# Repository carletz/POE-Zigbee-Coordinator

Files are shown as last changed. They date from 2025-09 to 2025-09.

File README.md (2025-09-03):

# Zigbee Coordinator with Ethernet and PoE Support

This project is a custom-designed Zigbee Coordinator board integrating **ESP32**, **Zigbee RF module (RF-BM-2652P2)**, and **Ethernet with Power over Ethernet (PoE)** capabilities. It is optimized for smart home or industrial IoT gateway applications, and provides a compact, PoE-powered solution for reliable Zigbee-to-IP bridging.

## Features

- **ESP32-WROOM-32UE** microcontroller with Wi-Fi and Bluetooth
- **Zigbee RF module (CC2652-based)** for Zigbee 3.0 coordination
- **LAN8720A Ethernet PHY** connected to ESP32 via RMII
- **PoE power supply** using TPS2376DDAR IEEE 802.3af-compliant PD controller
- Fully isolated and filtered power stages for 3.3V and 5V rails
- **CH340C USB-UART converter** for easy flashing/debugging
- USB Type-C input with ESD protection
- JTAG and serial debug headers
- LEDs for link/activity indication
- Compact design ready for fabrication via JLCPCB

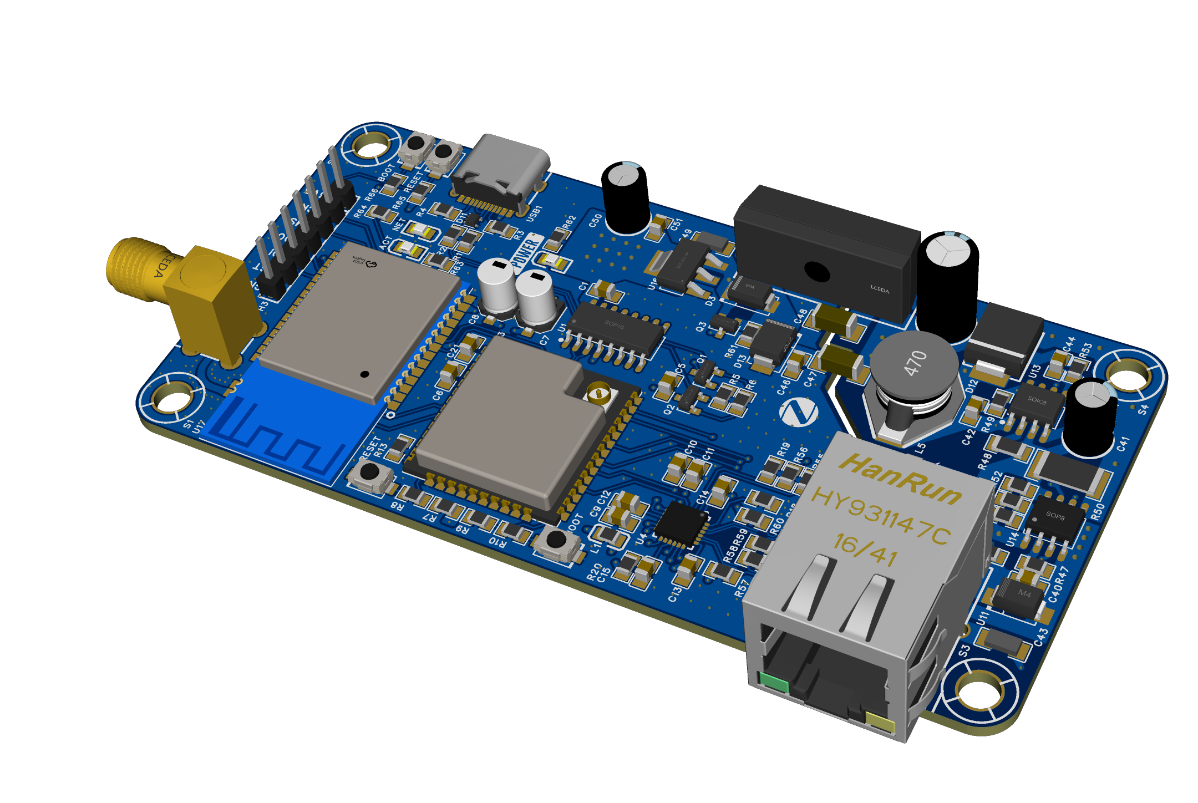
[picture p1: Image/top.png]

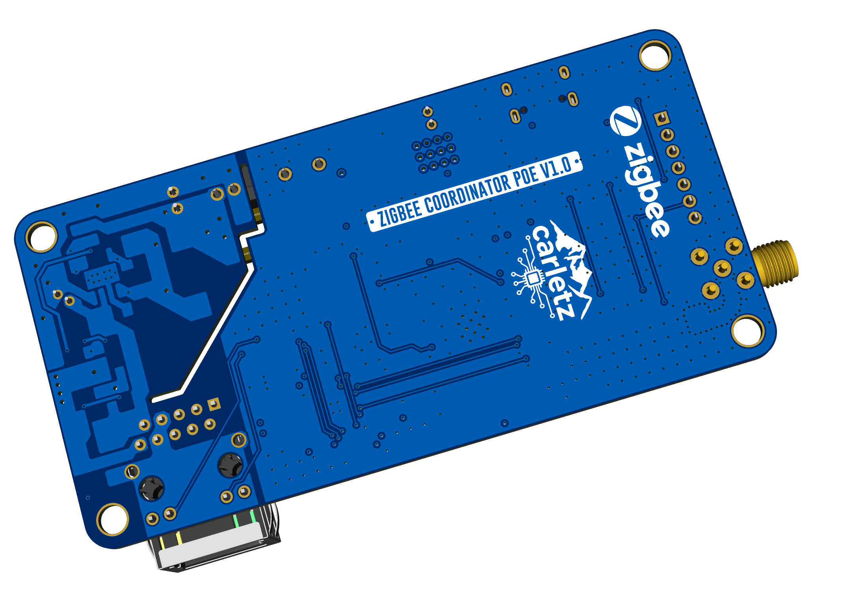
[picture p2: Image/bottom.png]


## Project Structure

The electrical schematic is divided into the following pages:
1. **Ethernet & PoE**: LAN8720A, RJ45 + magnetics, PoE PD and DC/DC conversion
2. **Controller**: ESP32 core, CH340C UART, USB input, power rails
3. **Zigbee Module**: RF-BM-2652P2, antenna, buttons, debug interfaces

## Tools & Compatibility

- Designed in **EasyEDA**
- Compatible with **Zigbee2MQTT**, **Home Assistant**, **OpenHAB**, and other automation platforms
- ESP32 flashable via USB or UART boot mode (IO0 + EN)
- Zigbee module (CC2652P2) flashable via UART bridge with ESP32

## Flashing Instructions

### ESP32
1. Flash the ESP32 using a serial tool or over USB with your preferred firmware (e.g., ESPHome, custom UART bridge, etc.).
   A special thanks to the work of [ZigStar](https://zig-star.com/) crew where I took a lot of inspiration

### CC2652P2 Zigbee Module
1. Use the ESP32 to create a UART bridge to the CC2652P2 module.
2. Access the ESP32 on the configured IP address via TCP/UDP.
3. Download the appropriate Zigbee coordinator firmware from (in dev branch folder):
   [Koenkk Z-Stack firmware](https://github.com/Koenkk/Z-Stack-firmware/tree/dev/coordinator/Z-Stack_3.x.0/bin)
4. Flash the CC2652P2 using tools like `cc2538-bsl` or TI's SmartRF Flash Programmer through the ESP32 UART bridge.

## Getting Started

1. Assemble the PCB using the schematic and a compatible BOM.
2. Flash ESP32 and configure the Zigbee module as described above.
3. Connect the board via Ethernet or Wi-Fi.
4. Integrate with your MQTT broker and Zigbee network.

## License

This project is open hardware, released under the MIT License.

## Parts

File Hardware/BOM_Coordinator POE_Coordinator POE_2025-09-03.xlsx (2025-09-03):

No. | Quantity | Comment | Designator | Footprint | Value | Manufacturer Part | Manufacturer | Supplier Part | Supplier | LCSC Stock | LCSC Price | Primary Category | Secondary Category | Pin Count | JLCPCB Stock | JLCPCB Price | 3D Model Title | Device | Name | Unique ID | Convert to PCB | Add into BOM | Symbol | Layer | Mounting Style
1 | 3 | XL-2012SURC | ((POWER)),ACT,NET | LED0805-R-RD |  | XL-2012SURC | XINGLIGHT(成兴光) | C965812 | LCSC |  |  | Optoelectronics | LED Indication - Discrete | 2 | 798816 | 0.0008 | LED0805-RD-1 | XL-2012SURC | XL-2012SURC | gge156_1,gge305,gge306 |  | yes |  | T | SMT
2 | 4 | TS-1088-AR02016 | BOOT,BOOT,RESET,RESET | SW-SMD_L3.9-W3.0-P4.45 |  | TS-1088-AR02016 | XUNPU(讯普) | C720477 | LCSC |  |  | Switches | Tactile Switches | 2 | 369929 | 0.0061 | SW-SMD_L3.9-W2.9-H2.0-LS4.8 | TS-1088-AR02016 | TS-1088-AR02016 | gge95_1,gge98_1,gge98_2,gge98_3 |  | yes |  | T | SMT
3 | 10 | 100nF | C1,C11,C12,C13,C14,C15,C21,C40,C42,C51 | C0805 | 100nF | CL21B104KCFNNNE | SAMSUNG(三星) | C28233 | LCSC |  |  | Capacitors | Multilayer Ceramic Capacitors MLCC - SMD/SMT | 2 | 946782 | 0.0009 | C0805_L2.0-W1.3-H1.3 | CL21B104KCFNNNE | 100nF | gge212,gge212_1,gge212_2,gge212_3,gge212_4,gge213_2,gge214_2,gge216,gge216_2,gge251 |  | yes |  | T | SMT
4 | 1 | 1uF | C5 | C0805 | 1uF | HHV0805R7105K101NSLJ | Chinocera(华瓷) | C22367837 | LCSC |  |  | Capacitors | Multilayer Ceramic Capacitors MLCC - SMD/SMT | 2 | 71386 | 0.0037 | C0805_L2.0-W1.3-H1.3 | HHV0805R7105K101NSLJ | 1uF | gge251_1 |  | yes |  | T | SMT
5 | 3 | 10uF | C6,C9,C10 | C0805 | 10uF | CL21A106KOQNNNE | SAMSUNG(三星) | C1713 | LCSC |  |  | Capacitors | Multilayer Ceramic Capacitors MLCC - SMD/SMT | 2 | 1508588 | 0.0013 | C0805_L2.0-W1.3-H1.3 | CL21A106KOQNNNE | 10uF | gge199,gge199_1,gge200 |  | yes |  | T | SMT
6 | 2 | 10uF | C7,C8 | CAP-SMD_BD4.0-L4.3-W4.3-LS5.1-FD | 10uF | VE-100M1ATR-0405 | lelon(立隆) | C249449 | LCSC |  |  | Capacitors | Aluminum Electrolytic Capacitors - SMD | 2 | 1 | 0.0083 | CAP-SMD_BD4.0-L4.3-W4.3-LS5.1-FD | VE-100M1ATR-0405 | 10uF | gge137_1,gge138_1 |  | yes |  | T | SMT
7 | 1 | 15uF | C41 | CAP-TH_BD5.0-P2.00-D0.8-FD | 15uF | LKMB1102A150MF | Ymin(永铭) | C443117 | LCSC |  |  | Capacitors | Aluminum Electrolytic Capacitors - Leaded | 2 | 1593 | 0.009 | CAP-TH_D5.0×H7.0×P2.0 | LKMB1102A150MF | 15uF | gge269_1 |  | yes |  | T | DIP
8 | 1 | 1nF | C43 | C1206 | 1nF | HHV1206R7102K202NSLJ | Chinocera | C5186823 | LCSC |  |  | Capacitors | Multilayer Ceramic Capacitors MLCC - SMD/SMT | 2 | 0 | 0.0019 | C1206_L3.2-W1.6-H1.3 | CC1206KKX7RDBB102 | 1nF | gge275_1 |  | yes |  | T | SMT
9 | 1 | 12pF | C44 | C0805 | 12pF | 0805CG120J500NT | FH(风华) | C1792 | LCSC |  |  | Capacitors | Multilayer Ceramic Capacitors MLCC - SMD/SMT | 2 | 112563 | 0.0007 | C0805_L2.0-W1.3-H1.3 | 0805CG120J500NT_C1792 | 12pF | gge277_1 |  | yes |  | T | SMT
10 | 1 | 470uF | C45 | CAP-TH_BD6.3-P2.50-D1.0-FD | 470uF | NXB10V470M6.3*11 LO | SAMYOUNG(韩国三莹) | C371106 | LCSC |  |  | Capacitors | Aluminum Electrolytic Capacitors - Leaded | 2 | 61 | 0.0103 | CAP-TH_BD6.3-P2.50-D1.0-FD | NXB10V470M6.3*11 LO | 470uF | gge280_1 |  | yes |  | T | DIP
11 | 1 | 22uF | C46 | C0805 | 22uF | CL21A226MQQNNNE | SAMSUNG(三星) | C5674 | LCSC |  |  | Capacitors | Multilayer Ceramic Capacitors MLCC - SMD/SMT | 2 | 3551136 | 0.0016 | C0805_L2.0-W1.3-H1.3 | CL21A226MQQNNNE | 22uF | gge284_1 |  | yes |  | T | SMT
12 | 2 | 1nF | C47,C48 | C1808 | 1nF | 1808B102K302NT | FH(风华) | C967608 | LCSC |  |  | Capacitors | Multilayer Ceramic Capacitors MLCC - SMD/SMT | 2 | 17403 | 0.0077 | C1808_L4.5-W2.0-H2.0 | 1808B102K302NT | 1nF | gge307_1,gge308_1 |  | yes |  | T | SMT
13 | 1 | 10uF | C49 | C1206 | 10uF | CL31A106KBHNNNE | SAMSUNG(三星) | C13585 | LCSC |  |  | Capacitors | Multilayer Ceramic Capacitors MLCC - SMD/SMT | 2 | 2284429 | 0.0047 | C1206_L3.2-W1.6-H1.3 | CL31A106KBHNNNE | 10uF | gge48_1 |  | yes |  | T | SMT
14 | 1 | 10uF | C50 | CAP-TH_BD5.0-P2.00-D0.8-FD | 10uF | GR106M050D11RR0VK2FP0 | CX(承兴) | C78759 | LCSC |  |  | Capacitors | Aluminum Electrolytic Capacitors - Leaded | 2 | 2948 | 0.0021 | CAP-TH_D5.0×H7.0×P2.0 | GR106M050D11RR0VK2FP0 | 10uF | gge120_1 |  | yes |  | T | DIP
15 | 1 | 1N5819 | D3 | SMA_L4.4-W2.6-LS5.0-RD |  | 1N5819 | KEXIN(科信) | C437199 | LCSC |  |  | Diodes | Schottky Diodes | 2 | 160948 | 0.0026 | SMA_L4.4-W2.6-LS5.0-RD | 1N5819_C437199 | 1N5819 | gge261_1 |  | yes |  | T | SMT
16 | 1 | TPD2E2U06DRLR | D11 | SOT-553-5_L1.6-W1.2-P0.50-LS1.6-TL-1 |  | TPD2E2U06DRLR | TI(德州仪器) | C1972959 | LCSC |  |  | Circuit Protection | ESD and Surge Protection (TVS/ESD) | 5 | 8465 | 0.0351 | SOT-553-5_L1.6-W1.2-P0.50-LS1.6-TL-1 | TPD2E2U06DRLR | TPD2E2U06DRLR | gge302 |  | yes |  | T | SMT
17 | 1 | SS510C | D12 | SMC_L7.1-W6.2-LS8.1-R-RD |  | SS510C | FUXINSEMI | C908242 | LCSC |  |  | Diodes | Schottky Diodes | 2 | 2408 | 0.0083 | SMC_L7.1-W6.2-LS8.1-RD1 | SS510C | SS510C | gge272_1 |  | yes |  | T | SMT
18 | 1 | SMBJ6.0A | D13 | SMB_L4.6-W3.6-LS5.3-RD |  | SMBJ6.0A | Littelfuse(美国力特) | C83270 | LCSC |  |  | Circuit Protection | ESD and Surge Protection (TVS/ESD) | 2 | 8303 | 0.0147 | SMB_L4.6-W3.6-LS5.3-RD | SMBJ6.0A_C83270 | SMBJ6.0A | gge285_1 |  | yes |  | T | SMT
19 | 1 | HDR-M_2.54_1x7P | H3 | HDR-TH_7P-P2.54-V-M |  |  |  |  |  | 1574000 | 0.0058 | Connectors | Pin Headers | 7 |  |  | HDR-TH_7P-P2.54-M-LI-1X7P | HDR-M_2.54_1x7P |  | gge307 |  | yes |  | T | DIP
20 | 1 | BLM21PG220SN1D | L1 | L0805 |  | BLM21PG220SN1D | muRata(村田) | C88993 | LCSC |  |  | Filters | Ferrite Beads | 2 | 734 | 0.0024 | R0805_L2.0-W1.3-H0.6 | BLM21PG220SN1D | BLM21PG220SN1D | gge132 |  | yes |  | T | SMT
21 | 1 | 33uH | L5 | IND-SMD_L12.9-W9.8 | 33uH | SMSD0804-330MT | SXN(顺翔诺) | C286357 | LCSC |  |  | Inductors, Coils, Chokes | Power Inductors | 2 | 108 | 0.0277 | IND-SMD_L12.9-W9.8-H5.2 | SMSD0804-330MT | 33uH | gge276_1 |  | yes |  | T | SMT
22 | 2 | SS8050 | Q1,Q2 | SOT-23-3_L2.9-W1.3-P1.90-LS2.4-BR |  | SS8050 | JSMSEMI(杰盛微) | C916392 | LCSC |  |  | Transistors/Thyristors | Bipolar (BJT) | 3 | 324811 | 0.0011 | SOT-23-3P_L2.9-W1.3-H1.0-LS2.4-P0.95 | SS8050_C916392 | SS8050 | gge143,gge144 |  | yes |  | T | SMT
23 | 1 | WPM2015-3/TR | Q3 | SOT-23-3_L2.9-W1.3-P1.90-LS2.4-BR |  | WPM2015-3/TR | KUU | C6562215 | LCSC |  |  | Transistors/Thyristors | MOSFETs | 3 | 8641 | 0.0059 | SOT-23-3P_L2.9-W1.3-H1.0-LS2.4-P0.95 | WPM2015-3/TR_C6562215 | WPM2015-3/TR | gge262_1 |  | yes |  | T | SMT
24 | 2 | 10Ω | R1,R2 | R0805_NEW | 10Ω | 0805W8F100JT5E | UNI-ROYAL(厚声) | C17415 | LCSC |  |  | Resistors | Chip Resistor - Surface Mount | 2 | 1795596 | 0.0003 | R0805_L2.0-W1.3-H0.6 | 0805W8F100JT5E | 10Ω | gge250,gge250_1 |  | yes |  | T | SMT
25 | 2 | 5.1kΩ | R3,R4 | R0805 | 5.1kΩ | RC0805FR-075K1L | YAGEO(国巨) | C84375 | LCSC |  |  | Resistors | Chip Resistor - Surface Mount | 2 | 182252 | 0.0003 | R0805_L2.0-W1.3-H0.6 | RC0805FR-075K1L | 5.1kΩ | gge300,gge301 |  | yes |  | T | SMT
26 | 2 | 12kΩ | R5,R6 | R0805 | 12kΩ | 0805W8J0123T5E | UNI-ROYAL(厚声) | C25616 | LCSC |  |  | Resistors | Chip Resistor - Surface Mount | 2 | 9441 | 0.0002 | R0805_L2.0-W1.3-H0.6 | 0805W8J0123T5E | 12kΩ | gge261,gge262 |  | yes |  | T | SMT
27 | 8 | 10kΩ | R7,R9,R13,R19,R20,R51,R61,R65 | R0805 | 10kΩ | RC0805FR-7W10KL | YAGEO(国巨) | C17414 | LCSC |  |  | Resistors | Chip Resistor - Surface Mount | 2 | 17206004 | 0.0003 | R0805_L2.0-W1.3-H0.6 | RC0805FR-7W10KL | 10kΩ | gge202_3,gge204,gge204_1,gge224_1,gge225,gge225_1,gge225_2,gge225_3 |  | yes |  | T | SMT
28 | 3 | 100Ω | R8,R10,R66 | R0805 | 100Ω | AC0805FR-7W100RL | YAGEO(国巨) | C727982 | LCSC |  |  | Resistors | Chip Resistor - Surface Mount | 2 | 58 | 0.0013 | R0805_L2.0-W1.3-H0.6 | AC0805FR-7W100RL | 100Ω | gge252,gge252_1,gge253 |  | yes |  | T | SMT
29 | 1 | 12.1kΩ | R18 | R0805 | 12.1kΩ | 0805W8F1212T5E | UNI-ROYAL(厚声) | C17431 | LCSC |  |  | Resistors | Chip Resistor - Surface Mount | 2 | 5451 | 0.0003 | R0805_L2.0-W1.3-H0.6 | 0805W8F1212T5E | 12.1kΩ | gge254 |  | yes |  | T | SMT
30 | 1 | 180kΩ | R46 | R0805 | 180kΩ | FRC0805F1803TS | FOJAN(富捷) | C2907230 | LCSC |  |  | Resistors | Chip Resistor - Surface Mount | 2 | 68098 | 0.0003 | R0805_L2.0-W1.3-H0.6 | FRC0805F1271TS | 180kΩ | gge266_1 |  | yes |  | T | SMT
31 | 1 | 4.42kΩ | R47 | R0805 | 4.42kΩ | FRC0805F4421TS | FOJAN(富捷) | C2960870 | LCSC |  |  | Resistors | Chip Resistor - Surface Mount | 2 | 11799 | 0.0003 | R0805_L2.0-W1.3-H0.6 | FRC0805F6652TS | 4.42kΩ | gge267_1 |  | yes |  | T | SMT
32 | 1 | 30mΩ | R48 | R1206 | 30mΩ | PA1206FRF470R03L | YAGEO(国巨) | C728293 | LCSC |  |  | Resistors | Chip Resistor - Surface Mount | 2 | 15 | 0.009 | R1206_L3.2-W1.6-H0.6 | PA1206FRF470R03L | 30mΩ | gge270_1 |  | yes |  | T | SMT
33 | 1 | 4.7Ω | R49 | R0805 | 4.7Ω | FRC0805F4R70TS | FOJAN(富捷) | C2907327 | LCSC |  |  | Resistors | Chip Resistor - Surface Mount | 2 | 9483 | 0.0002 | R0805_L2.0-W1.3-H0.6 | FRC0805F4R70TS | 4.7Ω | gge271_1 |  | yes |  | T | SMT
34 | 1 | 4.7kΩ | R50 | R2512 | 4.7kΩ | FRC2512J472 TS | FOJAN | C2907583 | LCSC |  |  | Resistors | Chip Resistor - Surface Mount | 2 | 16070 | 0.0027 | R2512_L6.3-W3.2-H0.6 | 25121WF4701T4E | 4.7kΩ | gge274_1 |  | yes |  | T | SMT
35 | 1 | 130kΩ | R52 | R0805 | 130kΩ | FRC0805F1303TS | FOJAN | C2933305 | LCSC |  |  | Resistors | Chip Resistor - Surface Mount | 2 | 18123 | 0.0003 | R0805_L2.0-W1.3-H0.6 | RC0805FR-7W10KL | 130kΩ | gge202_4 |  | yes |  | T | SMT
36 | 1 | 56.2kΩ | R53 | R0805 | 56.2kΩ | FRC0805F5622TS | FOJAN(富捷) | C2933471 | LCSC |  |  | Resistors | Chip Resistor - Surface Mount | 2 | 1160 | 0.0003 | R0805_L2.0-W1.3-H0.6 | FRC0805F5622TS | 56.2kΩ | gge278_1 |  | yes |  | T | SMT
37 | 1 | 10.5kΩ | R54 | R0805 | 10.5kΩ | FRC0805F1052TS | FOJAN | C2960821 | LCSC |  |  | Resistors | Chip Resistor - Surface Mount | 2 | 34 | 0.0003 | R0805_L2.0-W1.3-H0.6 | FRC0805F5622TS | 10.5kΩ | gge279_1 |  | yes |  | T | SMT
38 | 2 | 510Ω | R55,R56 | R0805 | 510Ω | FRC0805J511 TS | FOJAN(富捷) | C2907333 | LCSC |  |  | Resistors | Chip Resistor - Surface Mount | 2 | 28589 | 0.0002 | R0805_L2.0-W1.3-H0.6 | FRC0805J511 TS | 510Ω | gge235_1,gge235_3 |  | yes |  | T | SMT
39 | 4 | 49.9Ω | R57,R58,R59,R60 | R0805 | 49.9Ω | 0805W8F499JT5E | UNI-ROYAL(厚声) | C17720 | LCSC |  |  | Resistors | Chip Resistor - Surface Mount | 2 | 218069 | 0.0003 | R0805_L2.0-W1.3-H0.6 | 0805W8F499JT5E | 49.9Ω | gge238_5,gge238_6,gge238_7,gge238_8 |  | yes |  | T | SMT
40 | 1 | 2kΩ | R62 | R0805 | 2kΩ | 0805W8J0202T5E | UNI-ROYAL(厚声) | C1359 | LCSC |  |  | Resistors | Chip Resistor - Surface Mount | 2 | 164384 | 0.0002 | R0805_L2.0-W1.3-H0.6 | 0805W8J0202T5E | 2kΩ | gge253_1 |  | yes |  | T | SMT
41 | 2 | 1kΩ | R63,R64 | R0805 | 1kΩ | 0805W8F1001T5E | UNI-ROYAL(厚声) | C17513 | LCSC |  |  | Resistors | Chip Resistor - Surface Mount | 2 | 7428003 | 0.0003 | R0805_L2.0-W1.3-H0.6 | 0805W8F1001T5E | 1kΩ | gge158_1,gge158_3 |  | yes |  | T | SMT
42 | 1 | KH-SMA-K513-G | RF1 | ANT-TH_KH-SMA-K513-G |  | KH-SMA-K513-G | kinghelm(金航标) | C411575 | LCSC |  |  | Connectors | Coaxial Connectors (RF) | 5 | 15757 | 0.0808 | ANT-TH_L14.8-W6.4-H10.0 | KH-SMA-K513-G | KH-SMA-K513-G | gge304 |  | yes |  | T | DIP
43 | 1 | HY931147C | RJ2 | RJ45-TH_HY931147C |  | HY931147C | HANRUN(汉仁) | C91754 | LCSC |  |  | Connectors | Ethernet Connectors / Modular Connectors (RJ45 RJ11) | 16 | 2 | 0.327 | RJ45-TH_HY931147C | HY931147C | HY931147C | gge263_2 |  | yes |  | T | DIP
44 | 1 | CH340C | U1 | SOP-16_L10.0-W3.9-P1.27-LS6.0-BL |  | CH340C | WCH(南京沁恒) | C84681 | LCSC |  |  | Interface | USB Converters | 16 | 9622 | 0.0744 | SOP-16_L9.9-W3.9-H1.5-LS6.0-P1.27 | CH340C | CH340C | gge140 |  | yes |  | T | SMT
45 | 1 | ESP32-WROOM-32UE-N8 | U3 | WIFI-SMD_ESP32-WROOM-32UE |  | ESP32-WROOM-32UE-N8 | ESPRESSIF(乐鑫) | C701345 | LCSC |  |  | IoT/Communication Modules | WiFi Modules | 47 | 2195 | 0.4766 | WIFI-SMD_L19.2-18.0-H3.2-ESP32-WROOM-32UE | ESP32-WROOM-32UE-N8 | ESP32-WROOM-32UE-N8 | gge134 |  | yes |  | T | SMT
46 | 1 | LAN8720A-CP-TR-ABC | U4 | QFN-24_L4.0-W4.0-P0.50-TL-EP2.5 |  | LAN8720A-CP-TR-ABC | MICROCHIP(美国微芯) | C621419 | LCSC |  |  | Interface | Ethernet Transceivers | 25 | 273 | 0.1687 | QFN-24_L4.0-W4.0-P0.50-TL-EP2.1 | LAN8720A-CP-TR-ABC | LAN8720A-CP-TR-ABC | gge131 |  | yes |  | T | SMT
47 | 1 | SMAJ58A | U11 | SMA_L4.3-W2.7-LS5.0-RD |  | SMAJ58A | GOODWORK(固得沃克) | C2980408 | LCSC |  |  | Circuit Protection | ESD and Surge Protection (TVS/ESD) | 2 | 7991 | 0.0034 | SMA_L4.3-W2.7-LS5.0-RD | SMAJ58A_C2980408 | SMAJ58A | gge264_1 |  | yes |  | T | SMT
48 | 1 | 24.9kΩ | U12 | R0805 | 24.9kΩ | FRC0805F2492TS | FOJAN(富捷) | C2930185 | LCSC |  |  | Resistors | Chip Resistor - Surface Mount | 2 | 602 | 0.0003 | R0805_L2.0-W1.3-H0.6 | FRC0805F2492TS | 24.9kΩ | gge265_1 |  | yes |  | T | SMT
49 | 1 | TX4138 | U13 | SOIC-8_L4.9-W3.9-P1.27-LS6.0-BL-EP |  | TX4138 | XDS(芯鼎盛) | C329267 | LCSC |  |  | Power Management (PMIC) | DC-DC Converters | 9 | 8390 | 0.1065 | SOIC-8_L4.9-W3.9-H1.7-LS6.0-P1.27 | TX4138 | TX4138 | gge268_1 |  | yes |  | T | SMT
50 | 1 | TPS2376DDAR-H | U14 | SO-8_L4.9-W3.9-P1.27-LS6.0-BL-EP |  | TPS2376DDAR-H | TI(德州仪器) | C544899 | LCSC |  |  | Power Management (PMIC) | Power Over Ethernet (PoE) Controllers | 9 | 596 | 0.1164 | SO-8_L4.9-W3.9-H1.5-LS5.9-P1.27 | TPS2376DDAR-H | TPS2376DDAR-H | gge273_1 |  | yes |  | T | SMT
51 | 1 | F0505S-2WR2 | U15 | PWRM-TH_FXXXXS-1WR2 |  | F0505S-2WR2 | DEXU(德旭电子) | C909777 | LCSC |  |  | Power Modules | Isolated Power Modules | 4 | 85 | 0.1869 | PWRM-TH_FXXXXS-1WR2 | F0505S-2WR2 | F0505S-2WR2 | gge281_1 |  | yes |  | T | DIP
52 | 1 | BL1117-33CX | U16 | SOT-223-4_L6.5-W3.5-P2.30-LS7.0-BR |  | BL1117-33CX | BL(上海贝岭) | C5400 | LCSC |  |  | Power Management (PMIC) | Voltage Regulators - Linear, Low Drop Out (LDO) Regulators | 4 | 98142 | 0.0071 | SOT-223-4P_L6.5-W3.5-H1.6-LS7.0-P2.30 | BL1117-33CX | BL1117-33CX | gge46_1 |  | yes |  | T | SMT
53 | 1 | RF-BM-2652P2 | U17 | WIRELM-SMD_L30.0-W16.4_RF-BM-2652P1A |  | RF-BM-2652P2 | RF-star(信驰达) | C5440064 | LCSC |  |  | IoT/Communication Modules | Bluetooth Modules | 30 | 34 | 0.869 | WIRELM-SMD_L30.0-W16.4_RF-BM-2652P1A | RF-BM-2652P2_C5440064 | RF-BM-2652P2 | gge303 |  | yes |  | T | SMT
54 | 1 | TYPE-C 16PIN 2MD(073) | USB1 | USB-C-SMD_TYPE-C-6PIN-2MD-073 |  | TYPE-C 16PIN 2MD(073) | SHOU HAN(首韩) | C2765186 | LCSC |  |  | Connectors | USB Connectors | 16 | 568960 | 0.0081 | USB-C-SMD_TYPE-C-6PIN-2MD-073 | TYPE-C 16PIN 2MD(073) | TYPE-C 16PIN 2MD(073) | gge130_1 |  | yes |  | T | DIP

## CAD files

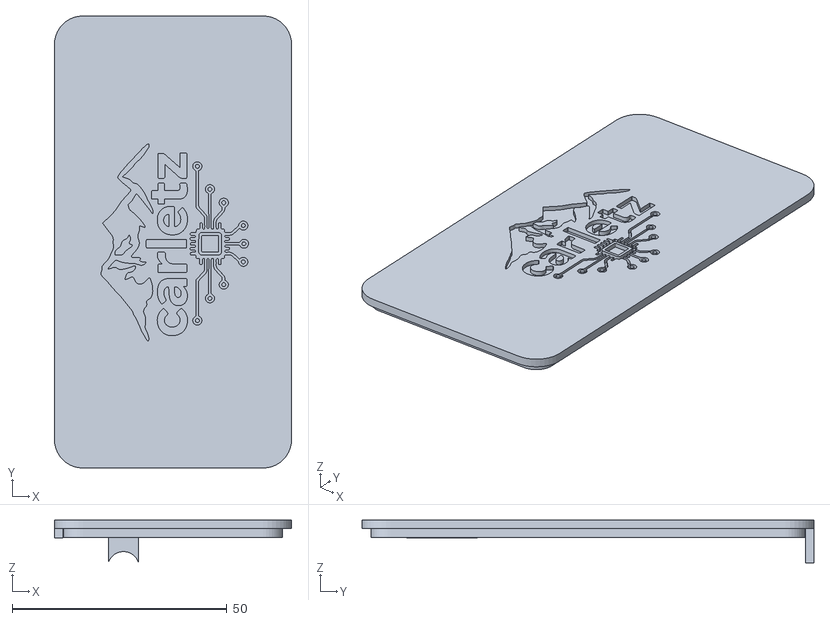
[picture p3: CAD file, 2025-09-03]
3D design/SCSOPRA^COORDINATOR.STL
55.2 x 105.2 x 9.97

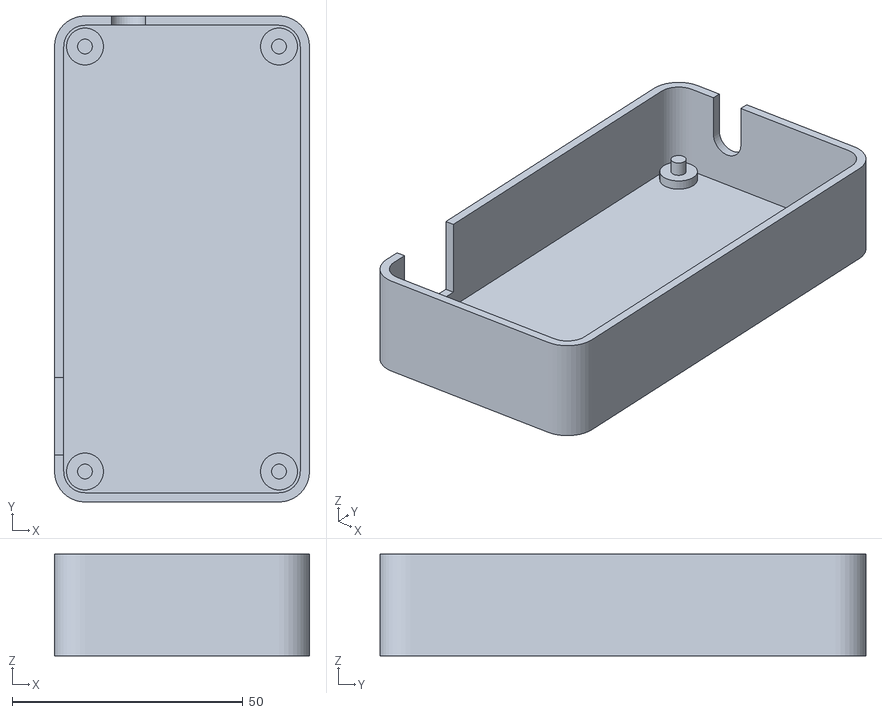
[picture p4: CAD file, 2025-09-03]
3D design/SCSOTTO^COORDINATOR.STL
55.2 x 105.2 x 22.0

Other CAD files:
3D design/SCSOPRA.SLDPRT

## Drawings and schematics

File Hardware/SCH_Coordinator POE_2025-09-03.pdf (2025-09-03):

# Ethernet

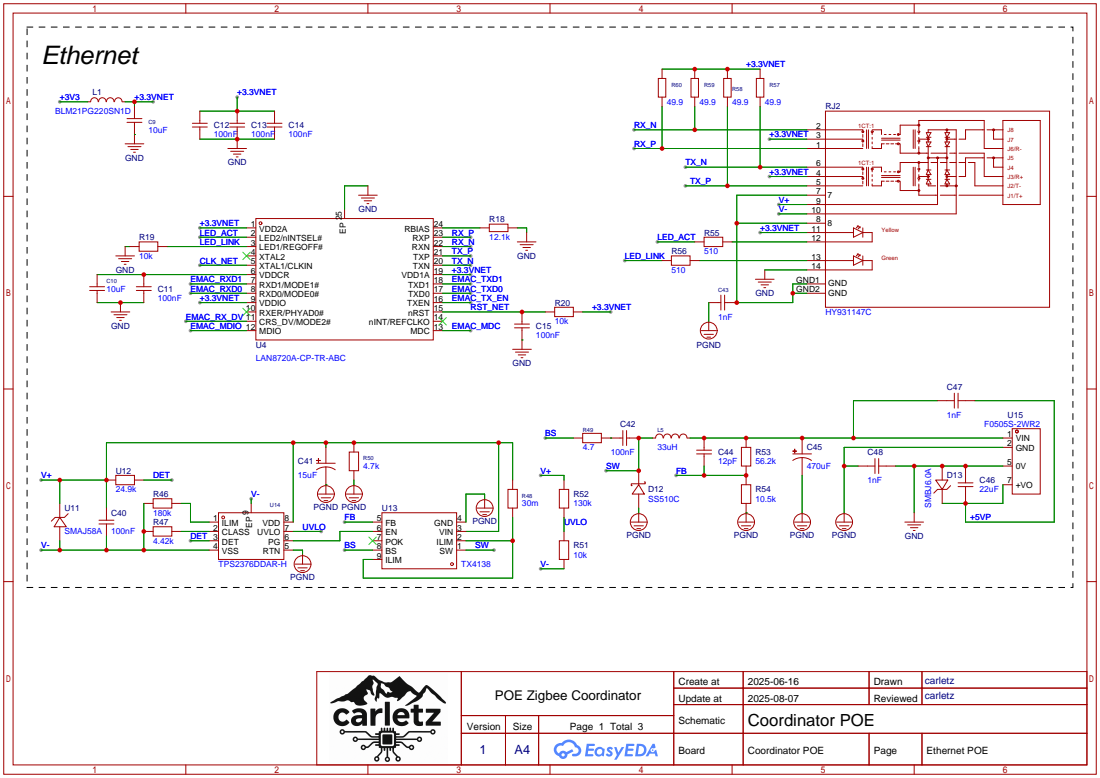
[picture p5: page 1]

POE Zigbee Coordinator | Create at | 2025-06-16 | Drawn | carletz

Update at | 2025-08-07 | Reviewed | carletz

Schematic | Coordinator POE
1 | A4 | | Board | Coordinator POE | Page | Ethernet POE

Version | Size | Page 1 Total 3

# USB Board Power supply

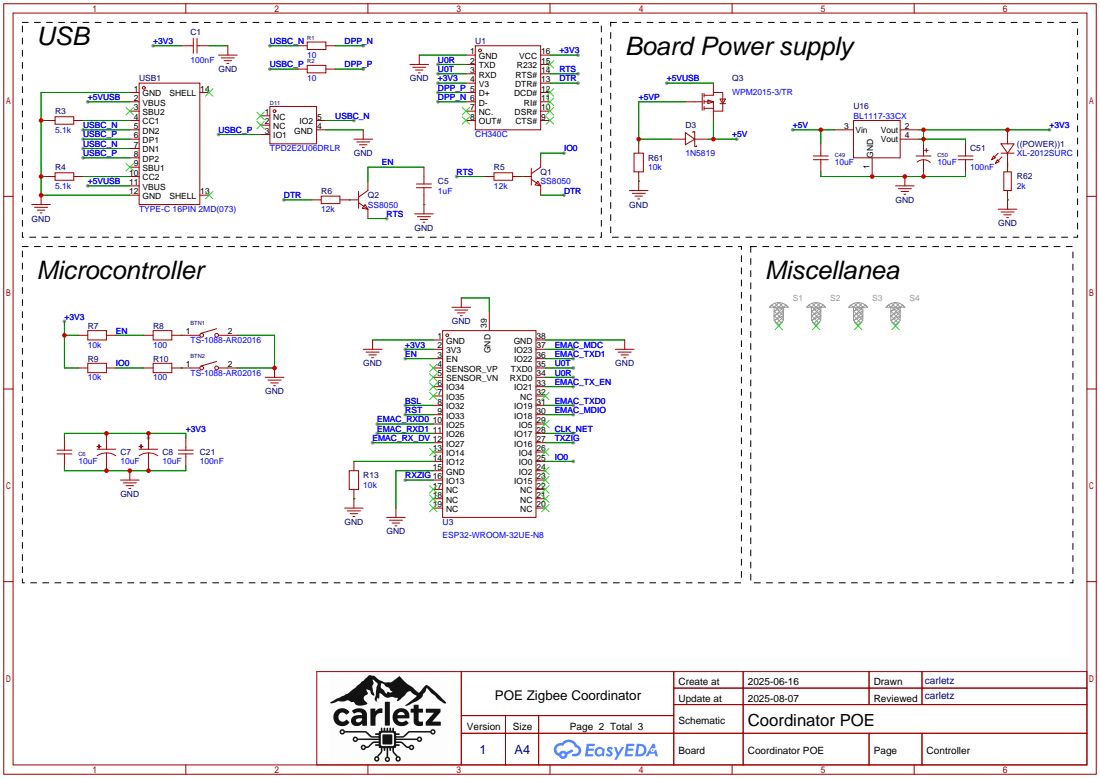
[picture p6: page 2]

DSR# 10 RI# 11 DCD# 12 DTR# 13 RTS# 14 R232 15 VCC 16

POE Zigbee Coordinator | Create at | 2025-06-16 | Drawn | carletz

Update at | 2025-08-07 | Reviewed | carletz

Schematic | Coordinator POE

Version | Size | Page 2 Total 3

Board | Coordinator POE | Page | Controller

# Zigbee

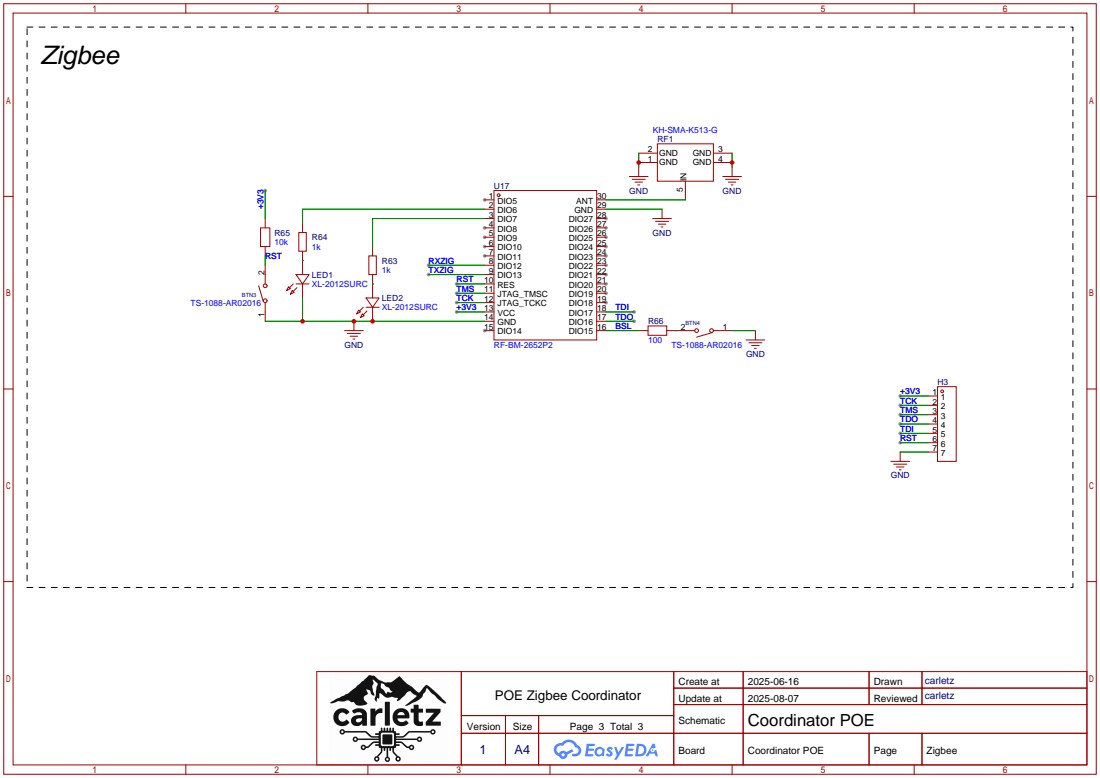
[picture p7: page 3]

POE Zigbee Coordinator | Create at | 2025-06-16 | Drawn | carletz

Update at | 2025-08-07 | Reviewed | carletz

Schematic | Coordinator POE

Version | Size | Page 3 Total 3

Board | Coordinator POE | Page | Zigbee

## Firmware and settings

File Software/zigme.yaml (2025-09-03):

substitutions:
  #Name your Gateway
  device_name: carletz-zigbee
  #Home Assistant Name
  friendly_name: Carletz Gateway

esphome:
  name: "${device_name}"

esp32:
  board: esp32dev
  framework:
    type: esp-idf #arduino

#Ethernet connection information
ethernet:
  type:  LAN8720
  mdc_pin: GPIO23
  mdio_pin: GPIO18
  clk_mode: GPIO17_OUT
  phy_addr: 0
  power_pin: GPIO12
  manual_ip:
    static_ip: 192.168.1.XXX      # change for your use
    gateway: 192.168.1.1
    subnet: 255.255.255.0

ota:
  - platform: esphome
    password: ""

## General ESPHome settings
# Logger is enabled
logger:
  level: DEBUG

# Enable WEB
web_server:
  port: 80
  version: 3
  
# Enable HA Time
time:
  - platform: sntp
    id: sntp_time
#   - platform: homeassistant
#     id: homeassistant_time

#External component Stream Server
external_components:
  - source: github://mercenaruss/esphome-stream-server

# Extra sensor to keep track of gateway uptime
text_sensor:
  - platform: template
    name: "${friendly_name} Uptime"
    lambda: |-
      uint32_t dur = id(uptime_s).state;
      int dys = 0;
      int hrs = 0;
      int mnts = 0;
      if (dur > 86399) {
        dys = trunc(dur / 86400);
        dur = dur - (dys * 86400);
      }
      if (dur > 3599) {
        hrs = trunc(dur / 3600);
        dur = dur - (hrs * 3600);
      }
      if (dur > 59) {
        mnts = trunc(dur / 60);
        dur = dur - (mnts * 60);
      }
      char buffer[17];
      sprintf(buffer, "%ud %02uh %02um %02us", dys, hrs, mnts, dur);
      return {buffer};
    update_interval: 60s

#Uptime
sensor:
  - platform: uptime
    id: uptime_s
    update_interval: 60s

# Device functions:
switch:
  - platform: restart
    name: "Gateway Restart"

  - platform: gpio
    pin: 33
    id: zRST_gpio
    inverted: yes
    restore_mode: ALWAYS_OFF
  - platform: template
    name: "Zigbee RST"
    id: zRST
    turn_on_action:
      - switch.turn_on: zRST_gpio
      - delay: 15ms
      - switch.turn_off: zRST_gpio
      
  - platform: gpio
    pin: 32
    name: "Zigbee BSL"
    id: zBSL
    inverted: yes
    restore_mode: ALWAYS_OFF
    internal: true
    
  - platform: template
    name: "Firmware Update"
    turn_on_action:
      - script.execute: fw_update_mode
    turn_off_action:
      - switch.toggle: zRST

# Update CC2652 Firmware
script:
  - id: fw_update_mode
    then:
      - switch.turn_on: zBSL
      - delay: 1s
      - switch.turn_on: zRST_gpio
      - delay: 1s
      - switch.turn_off: zRST_gpio
      - logger.log: "Delaying ~5 seconds for TI chip to be ready"
      - delay: 5s
      - switch.turn_off: zBSL
      - logger.log: "Update with cc2538-bsl tool now!"
      - logger.log: "Usage: cc2538_bsl.py -p socket://192.168.1.8:6638 -evw CC1352P2_CC2652P_launchpad_coordinator_20250321.hex"

#UART Settings
uart:
  id: uart_bus
  rx_pin: GPIO16
  tx_pin: GPIO13
  baud_rate: 115200

#Serial Bridge Settings,uncomment #port to change default 6638 TCP port
stream_server:
  uart_id: uart_bus
#  port: 1234
